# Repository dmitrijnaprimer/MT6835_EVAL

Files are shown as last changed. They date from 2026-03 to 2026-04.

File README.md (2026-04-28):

# MT6835_EVAL

Evaluation system for the MagnTek MT6835 21-bit magnetic encoder IC.

Measures MT6835 nonlinearity against a LIR-DA237T 23-bit optical reference encoder, computes NLC (Non-Linearity Compensation) correction tables, visualizes results.
Built as a platform for evaluation and a proof-of-concept, pieces of this work can be used for real in-system calibration fixtures.

## Used hardware

- **MCU:** STM32H503CBT6 (not recommended — any dual-SPI MCU will do)
- **Evaluated encoder:** MagnTek MT6835 (SPI, 21-bit)
- **Reference encoder:** LIR-DA237T (BiSS-C, 23-bit, ±0.0083°)
- **Motor driver:** TMC2225 (STEP/DIR, 32 microsteps)
- **Motor:** 400 steps/rev (0.9°), 12 800 microsteps/rev
- **Fixture:** ASA 3D-printed horisontal mechanical bench, 8mm main shaft, ball bearing holder.

Single-shaft fixture — both encoders and the stepper on the same shaft. Magnet is fixed on the shaft end via replaceable adapter. Adapters available for 4×2 mm round, 6×2.5 mm round, 6×6×6 mm cube magnets. Optimal air gap: 0.5–2.0 mm.

## Key findings

| Parameter | Value |
|---|---|
| NLC LSB | 360°/2¹⁸ = 0.001373° (8 counts of 21-bit angle) |
| NLC packing | MSB-first, 6-bit two's complement |
| NLC grid | indexed by raw magnetic angle (before ZERO_POS) |
| DC removal | chip subtracts the mean automatically |
| NLC range | ±0.044° per point (±32 LSB) |

## Quick Start — Python GUI

```bash
cd software
python -m venv .venv
source .venv/bin/activate
pip install -r requirements.txt
python main.py
```

## Quick Start — Firmware

### Prerequisites

- [ARM GNU Toolchain](https://developer.arm.com/downloads/-/arm-gnu-toolchain-downloads) (`arm-gnu-toolchain-15.2.rel1-x86_64-arm-none-eabi`)
- CMake ≥ 3.22
- Ninja (or another CMake generator)

### Build

```bash
cd firmware/MT6835_EVAL_STM32H503
cmake --preset=Debug
cmake --build --preset=Debug
```

Output: `build/Debug/MT6835_EVAL_01.elf` (`.bin`, `.hex`).

### Flash

Via ST-Link (OpenOCD, STM32CubeProgrammer, or `st-flash`):

```bash
st-flash write build/Debug/MT6835_EVAL_01.bin 0x08000000
```

Or load the `.elf` directly from IDE (STM32CubeIDE, VS Code + Cortex-Debug), or with CubeProgrammer.

## Evaluation workflow

1. **User Auto-Cal** — built-in MT6835 calibration at 50–100 RPM (gets INL to ~±0.07°)
2. **Home** — move shaft to LIR zero position
3. **Set Zero Pos** — set MT6835 ZERO_POS (must be done before NLC, never after)
4. **Collect Data** — stepped measurement at 256 positions across 360°
5. **Generate NLC** — computes correction table from collected error profile
6. **Upload NLC** — writes table to MT6835 registers + EEPROM
7. **Collect Data** again to verify improvement

## Project structure

```
software/         — Python GUI (PyQt5) + calibration logic
firmware/         — STM32 firmware (CMake, C)
data/             — collected CSV data (gitignored)
  nlc/            — generated NLC hex files (gitignored)
construction/     — mechanical STEP files (see note below)
docs/             — technical report, datasheets
```

### Construction files

The `construction/` folder contains individual STEP files for each 3D printed part — **no assembly file is provided**. These are reference geometry only.

## License

MIT

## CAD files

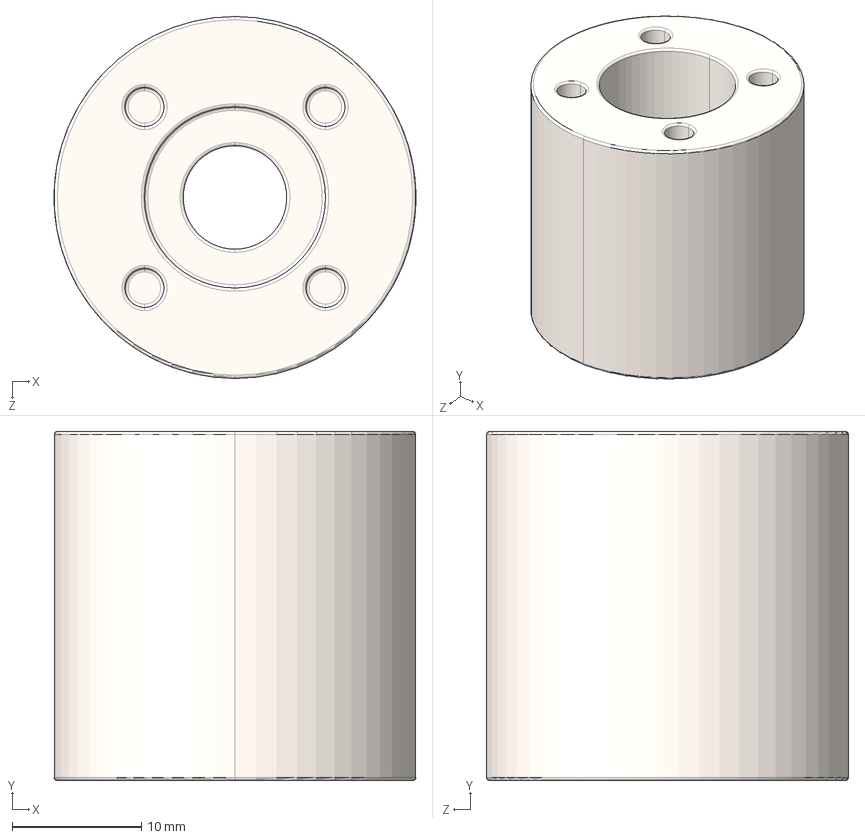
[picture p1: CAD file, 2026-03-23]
construction/STEP/shaft/main-shaft_bearing-block.STEP
28.0 x 27.0 x 28.0 mm

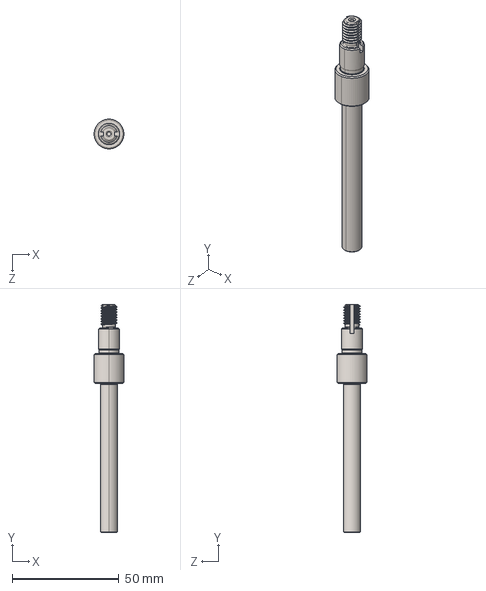
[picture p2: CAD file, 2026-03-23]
construction/STEP/shaft/main-shaft_shaft.STEP
14.0 x 107.0 x 14.0 mm

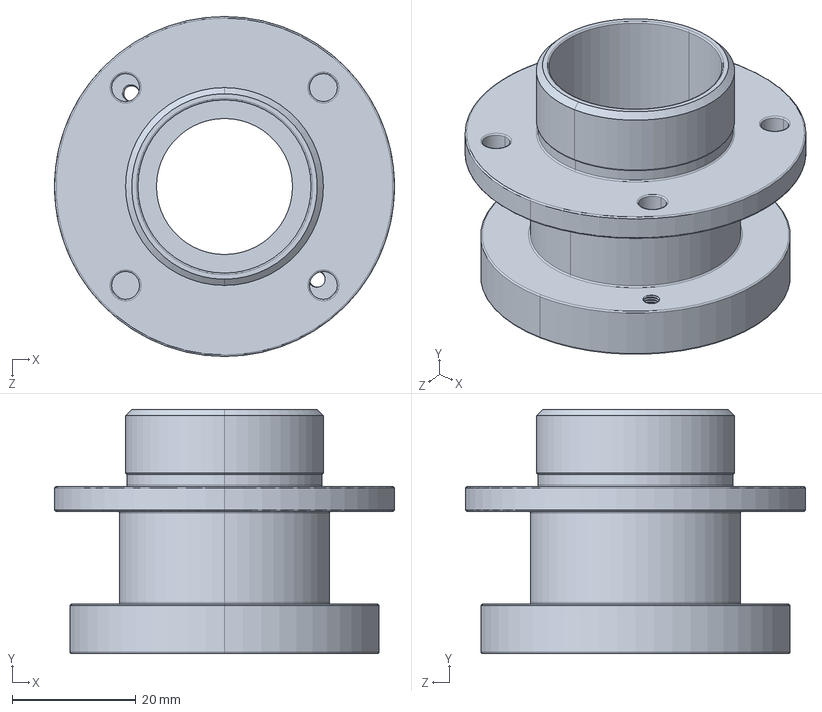
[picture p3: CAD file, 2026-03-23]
construction/STEP/shaft/main-shaft_flange.STEP
55.0 x 39.5 x 55.0 mm

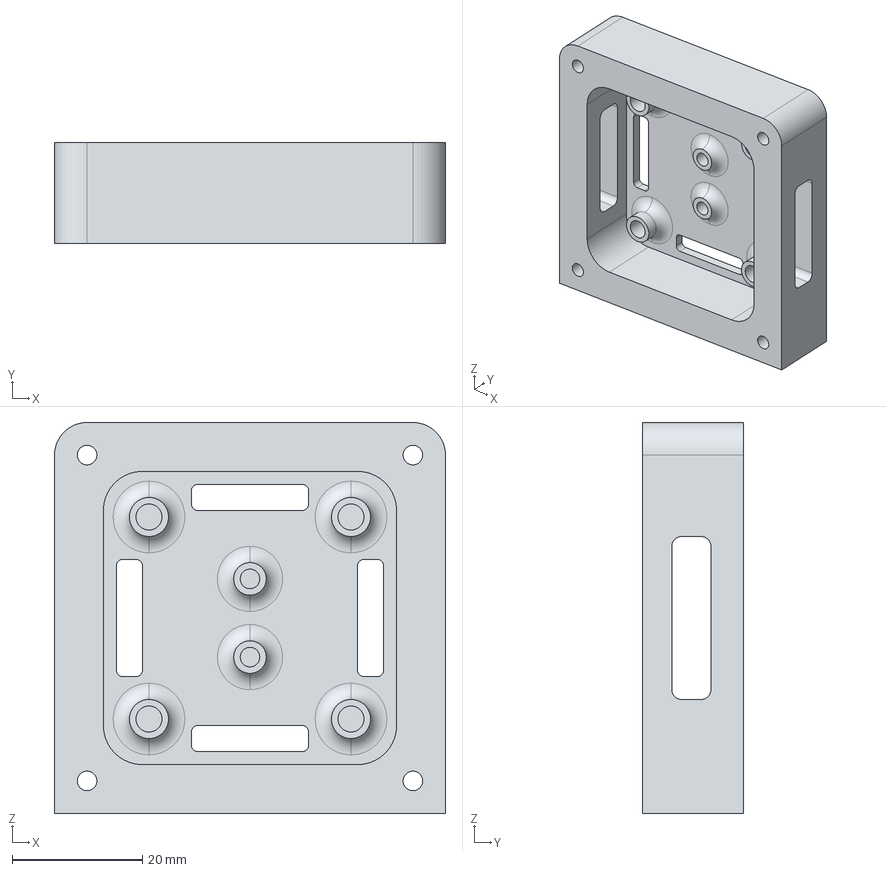
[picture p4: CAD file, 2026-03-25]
construction/STEP/encoder-stand_plastic/encoder-stand_magnetic-encoder-holder-base.STEP
60.0 x 15.5 x 60.0 mm

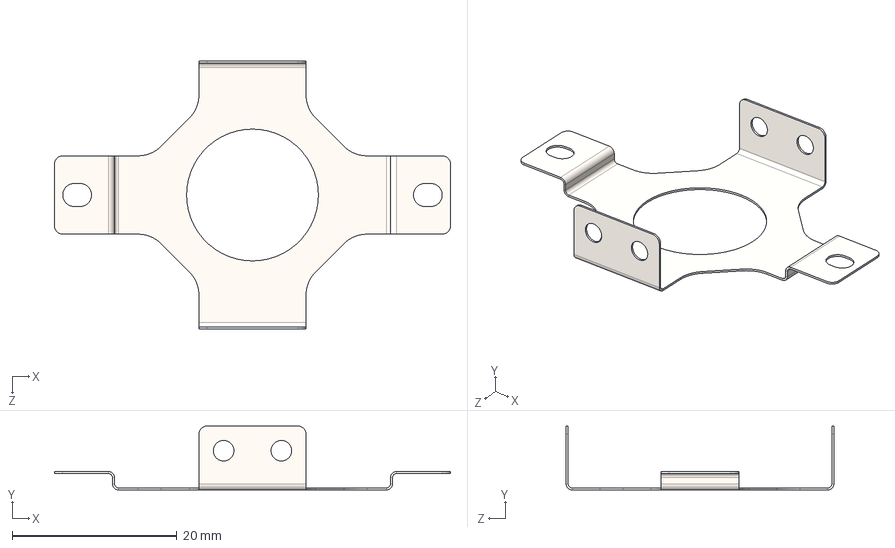
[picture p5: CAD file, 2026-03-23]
construction/STEP/LIR-DA237T/LIR-DA237T_CLIP.STEP
48.1 x 7.77 x 32.5 mm

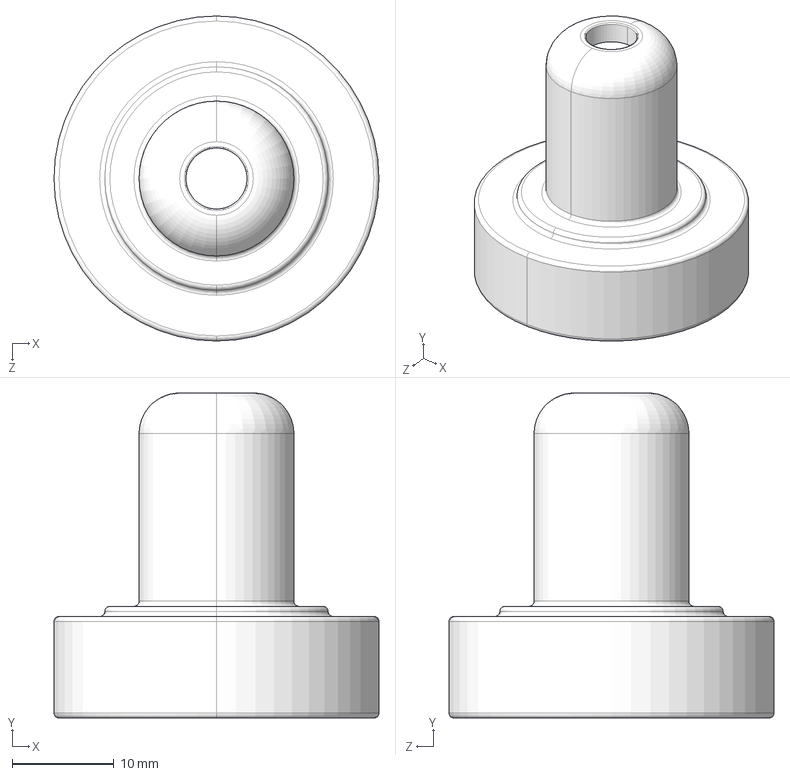
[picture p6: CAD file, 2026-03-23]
construction/STEP/encoder-stand_plastic/encoder-stand_magnet-holder_6x2.5-round.STEP
32.0 x 32.0 x 32.0 mm

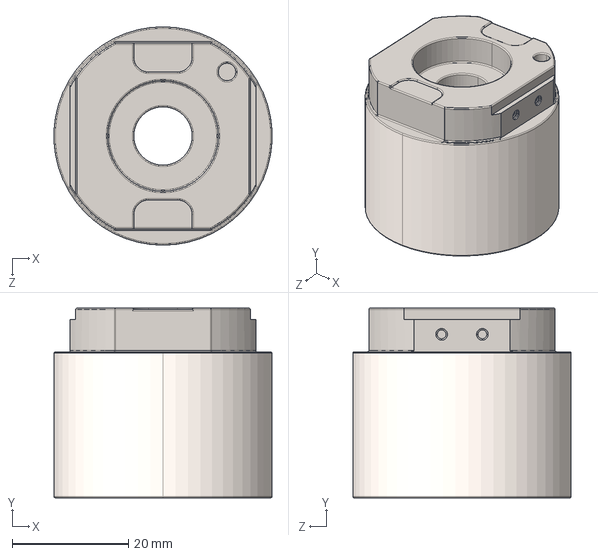
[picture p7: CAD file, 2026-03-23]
construction/STEP/LIR-DA237T/LIR-DA237T_BODY.STEP
37.4 x 32.6 x 37.5 mm

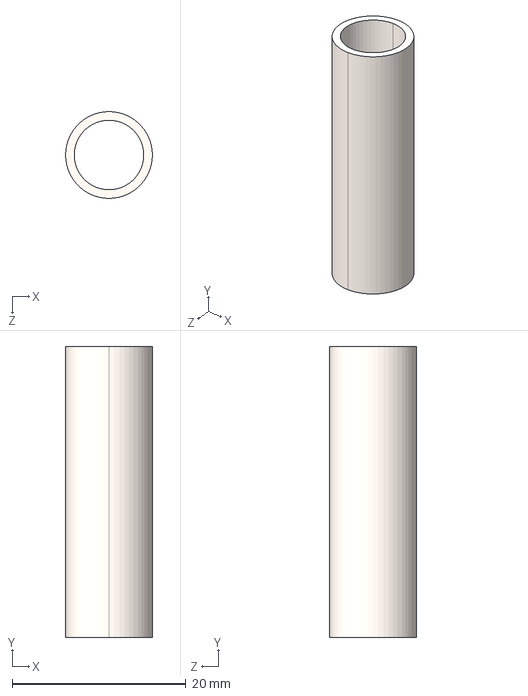
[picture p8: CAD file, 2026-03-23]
construction/STEP/LIR-DA237T/LIR-DA237T_SHAFT.STEP
10.0 x 33.5 x 10.0 mm

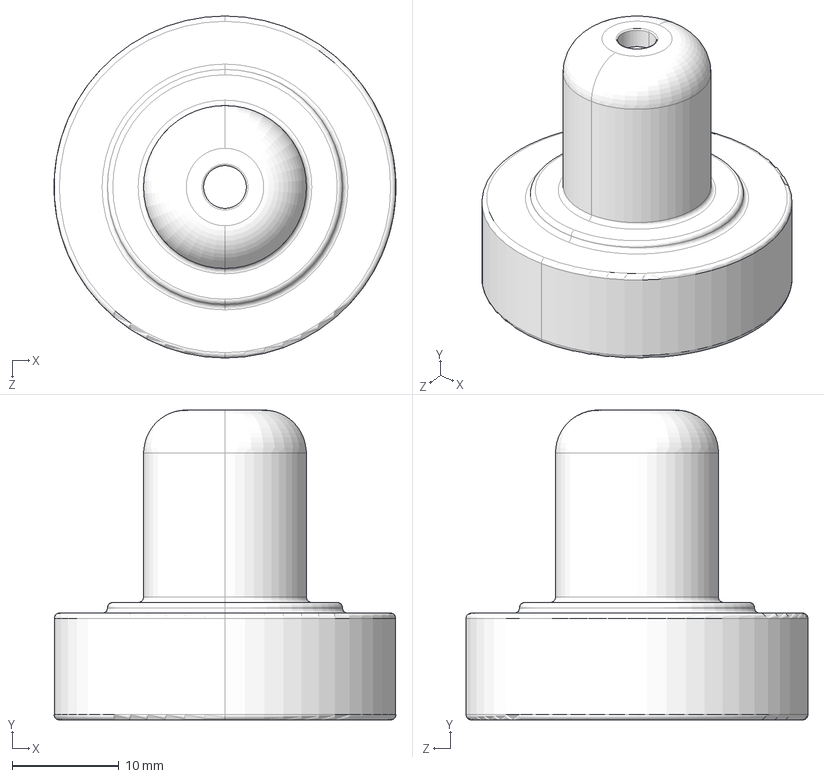
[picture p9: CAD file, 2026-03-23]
construction/STEP/encoder-stand_plastic/encoder-stand_magnet-holder_4x2-round_shortened.STEP
32.0 x 29.0 x 32.0 mm

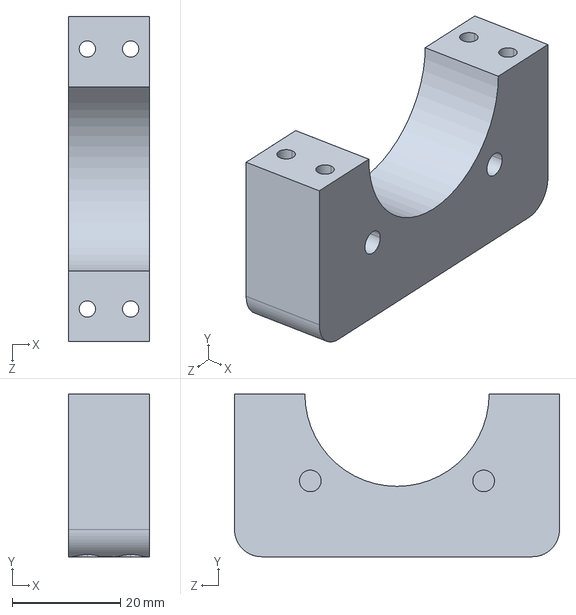
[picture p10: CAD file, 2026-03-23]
construction/STEP/encoder-stand_plastic/encoder-stand_flange-support-top.STEP
15.0 x 30.0 x 60.0 mm

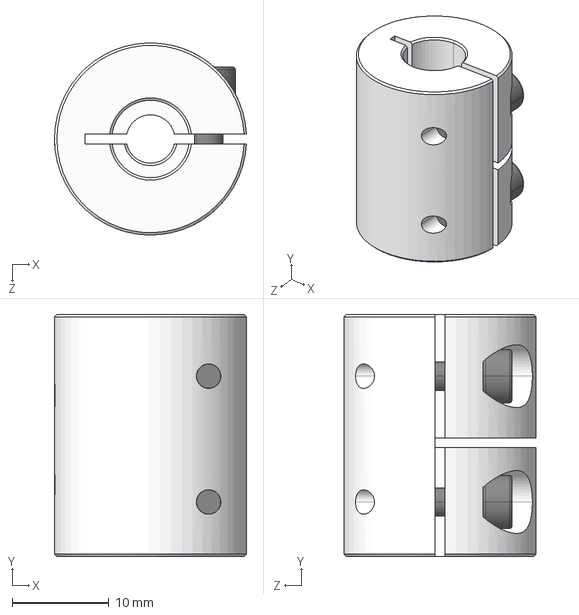
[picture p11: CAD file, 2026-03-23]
construction/STEP/shaft/5mm to 8mm rigid shaft coupler v2.STEP
19.8 x 25.0 x 19.8 mm

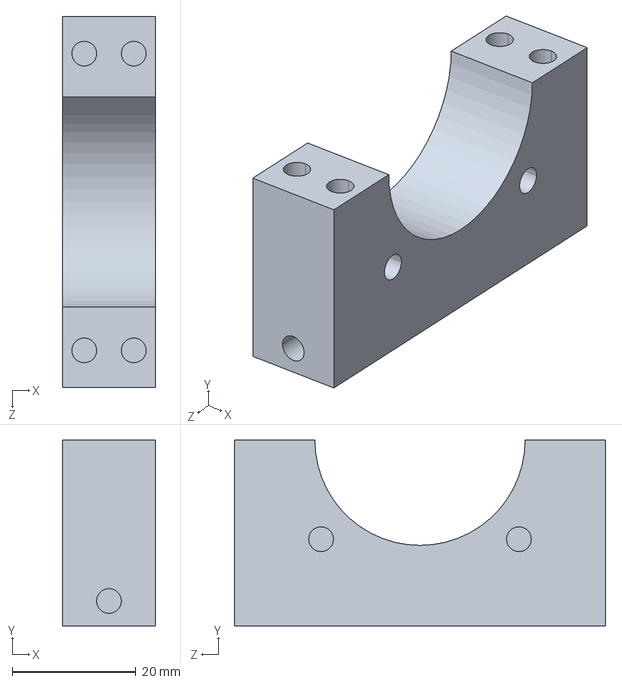
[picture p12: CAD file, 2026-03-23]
construction/STEP/encoder-stand_plastic/encoder-stand_flange-support-bottom.STEP
15.0 x 30.0 x 60.0 mm

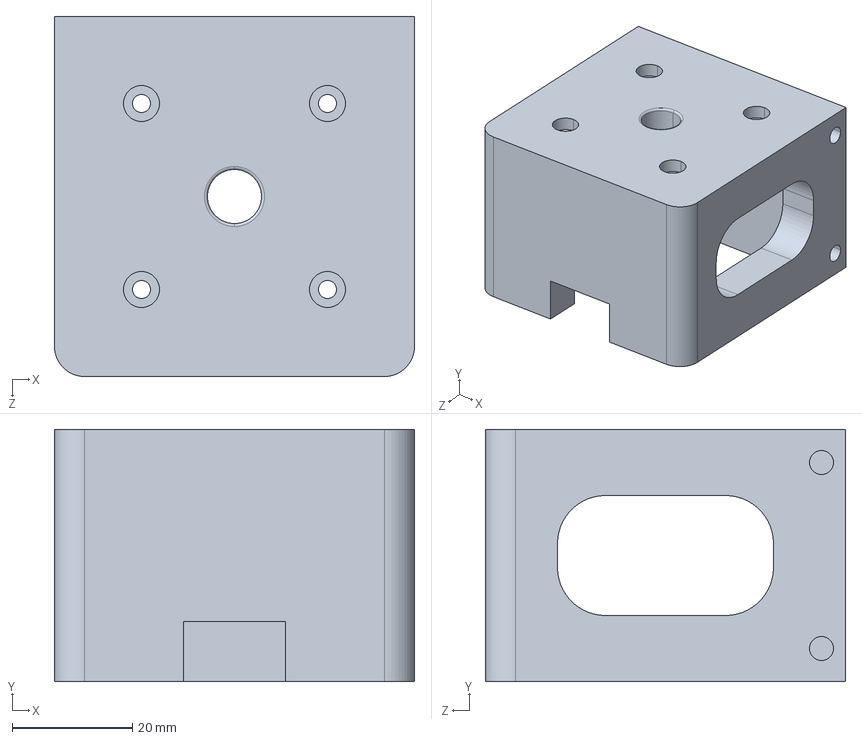
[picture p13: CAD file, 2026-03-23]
construction/STEP/encoder-stand_plastic/encoder-stand_motor-mount.STEP
60.0 x 42.0 x 60.0 mm

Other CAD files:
construction/STEP/shaft/main-shaft_assy.STEP
construction/STEP/encoder-stand_plastic/encoder-stand_bearing-support-assy.STEP
construction/STEP/encoder-stand_plastic/encoder-stand_flange-support-assy.STEP
construction/STEP/encoder-stand_plastic/encoder-stand_magnetic-encoder-holder-assy.STEP
construction/STEP/LIR-DA237T/LIR-DA237T.STEP
construction/STEP/encoder-stand_plastic/encoder-stand_base.STEP
construction/STEP/encoder-stand_plastic/encoder-stand_bearing-support-base.STEP
construction/STEP/encoder-stand_plastic/encoder-stand_magnet-holder_4x2-round.STEP
construction/STEP/encoder-stand_plastic/encoder-stand_magnet-holder_6x2.5-round_shortened.STEP
construction/STEP/encoder-stand_plastic/encoder-stand_magnet-holder_6x6-cube.STEP

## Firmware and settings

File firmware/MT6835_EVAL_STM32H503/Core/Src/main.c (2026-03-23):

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
/* Includes ------------------------------------------------------------------*/
#include "main.h"
#include "gpio.h"
#include "icache.h"
#include "spi.h"
#include "tim.h"
#include "usart.h"

/* USER CODE BEGIN Includes */
#include "encoders.h"
#include "motor_control.h"
#include "stm32h5xx_hal.h"
#include "uartcmd_handler.h"

/* USER CODE END Includes */


/* USER CODE BEGIN PV */
#define UART_RX_BUFFER_SIZE 512
char uart_rx_buffer[UART_RX_BUFFER_SIZE] = {0};
uint32_t uart_rx_index = 0;
bool uart_command_ready = false;
uint32_t led_blink_counter = 0;
bool homed_flag_for_led = false;
/* USER CODE END PV */

void SystemClock_Config(void);
void PeriphCommonClock_Config(void);
/**
 * @brief  The application entry point.
 * @retval int
 */
int main(void) {

  /* MCU Configuration--------------------------------------------------------*/

  /* Reset of all peripherals, Initializes the Flash interface and the Systick.
   */
  HAL_Init();

  /* Configure the system clock */
  SystemClock_Config();

  /* Configure the peripherals common clocks */
  PeriphCommonClock_Config();

  /* Initialize all configured peripherals */
  MX_GPIO_Init();
  MX_SPI1_Init();
  MX_TIM2_Init();
  MX_TIM3_Init();
  MX_USART1_UART_Init();
  MX_ICACHE_Init();
  MX_SPI2_Init();
  MX_TIM1_Init();
  /* USER CODE BEGIN 2 */
  ENC_Init();
  MC_Init();

  HAL_GPIO_WritePin(LED_3_GPIO_Port, LED_3_Pin, GPIO_PIN_RESET);
  HAL_GPIO_WritePin(LED_5_GPIO_Port, LED_5_Pin, GPIO_PIN_RESET);
  HAL_GPIO_WritePin(MT6835_CAL_EN_GPIO_Port, MT6835_CAL_EN_Pin, GPIO_PIN_RESET);
  HAL_GPIO_WritePin(LED_2_GPIO_Port, LED_2_Pin, GPIO_PIN_RESET);

  HAL_UART_Transmit(&huart1, (uint8_t *)"System Ready\n", 38, HAL_MAX_DELAY);
  /* USER CODE END 2 */

  /* Infinite loop */
  /* USER CODE BEGIN WHILE */
  while (1) {
    /* USER CODE END WHILE */

    /* USER CODE BEGIN 3 */
    if (HAL_GPIO_ReadPin(TMC2225_EN_GPIO_Port, TMC2225_EN_Pin) ==
        GPIO_PIN_RESET) {
      HAL_GPIO_WritePin(LED_4_GPIO_Port, LED_4_Pin,
                        GPIO_PIN_SET); // Motor enabled
    } else {
      HAL_GPIO_WritePin(LED_4_GPIO_Port, LED_4_Pin, GPIO_PIN_RESET);
    }

    if (homed_flag_for_led) {
      HAL_GPIO_WritePin(LED_0_GPIO_Port, LED_0_Pin, GPIO_PIN_SET); // Homed
    } else {
      HAL_GPIO_WritePin(LED_0_GPIO_Port, LED_0_Pin, GPIO_PIN_RESET);
    }

    led_blink_counter++;
    if (led_blink_counter >= 50000) {
      HAL_GPIO_TogglePin(LED_5_GPIO_Port, LED_5_Pin); // Slow blink
      led_blink_counter = 0;

      // Update LED 3 based on PWM Duty Cycle
      float pwm = ENC_GetMT6835PWMDutyCyclePercent();
      if (pwm > 95.0f) {
        HAL_GPIO_WritePin(LED_3_GPIO_Port, LED_3_Pin, GPIO_PIN_SET); // Solid ON
      } else if (pwm >= 25.0f && pwm <= 95.0f) {
        HAL_GPIO_TogglePin(LED_3_GPIO_Port, LED_3_Pin); // Blink
      } else {
        HAL_GPIO_WritePin(LED_3_GPIO_Port, LED_3_Pin, GPIO_PIN_RESET); // OFF
      }
    }

    if (HAL_GPIO_ReadPin(MT6835_CAL_EN_GPIO_Port, MT6835_CAL_EN_Pin) ==
        GPIO_PIN_SET) {
      HAL_GPIO_WritePin(LED_2_GPIO_Port, LED_2_Pin,
                        GPIO_PIN_SET); // MT6835 Cal enabled
    } else {
      HAL_GPIO_WritePin(LED_2_GPIO_Port, LED_2_Pin, GPIO_PIN_RESET);
    }

    uint8_t rx_char;
    if (HAL_UART_Receive(&huart1, &rx_char, 1, 0) == HAL_OK) {
      if (rx_char == '\n' || rx_char == '\r' ||
          uart_rx_index >= sizeof(uart_rx_buffer) - 1) {
        uart_rx_buffer[uart_rx_index] = '\0';
        if ((rx_char == '\n' || rx_char == '\r') && uart_rx_index > 0) {
          uart_command_ready = true;
        }
        uart_rx_index = 0;
      } else {
        uart_rx_buffer[uart_rx_index++] = rx_char;
      }
    }

    if (uart_command_ready) {
      UART_CMD_ProcessCommand(uart_rx_buffer);
      uart_command_ready = false;
      extern bool UART_CMD_GetHomedState(void);
      homed_flag_for_led = UART_CMD_GetHomedState();
    }
  }
  /* USER CODE END 3 */
}

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


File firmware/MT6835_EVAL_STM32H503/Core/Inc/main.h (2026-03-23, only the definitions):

#define MT6835_CSN_Pin GPIO_PIN_1
#define MT6835_CSN_GPIO_Port GPIOA
#define LED_0_Pin GPIO_PIN_3
#define LED_0_GPIO_Port GPIOA
#define MT6835_MOSI_Pin GPIO_PIN_4
#define MT6835_MOSI_GPIO_Port GPIOA
#define MT6835_SCK_Pin GPIO_PIN_5
#define MT6835_SCK_GPIO_Port GPIOA
#define LED_1_Pin GPIO_PIN_6
#define LED_1_GPIO_Port GPIOA
#define LED_2_Pin GPIO_PIN_7
#define LED_2_GPIO_Port GPIOA
#define LED_3_Pin GPIO_PIN_0
#define LED_3_GPIO_Port GPIOB
#define LIR_DA237T_SCK_Pin GPIO_PIN_2
#define LIR_DA237T_SCK_GPIO_Port GPIOB
#define LED_4_Pin GPIO_PIN_10
#define LED_4_GPIO_Port GPIOB
#define MT6835_CAL_EN_Pin GPIO_PIN_12
#define MT6835_CAL_EN_GPIO_Port GPIOB
#define MT6835_PWM_Pin GPIO_PIN_13
#define MT6835_PWM_GPIO_Port GPIOB
#define TMC2225_DIR_Pin GPIO_PIN_9
#define TMC2225_DIR_GPIO_Port GPIOA
#define TMC2225_EN_Pin GPIO_PIN_10
#define TMC2225_EN_GPIO_Port GPIOA
#define LIR_DA237T_DATA_Pin GPIO_PIN_15
#define LIR_DA237T_DATA_GPIO_Port GPIOA
#define TMC2225_STEP_Pin GPIO_PIN_3
#define TMC2225_STEP_GPIO_Port GPIOB
#define MT6835_MISO_Pin GPIO_PIN_4
#define MT6835_MISO_GPIO_Port GPIOB
#define TMC2225_MICROSTEPS_Pin GPIO_PIN_7
#define TMC2225_MICROSTEPS_GPIO_Port GPIOB
#define LED_5_Pin GPIO_PIN_8
#define LED_5_GPIO_Port GPIOB

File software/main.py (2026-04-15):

"""Encoder evaluation GUI for MT6835 motor control.

Provides serial communication with the eval board, motor control,
MT6835 configuration (HYST, BW, NLC, ZERO_POS), stepped data
collection, and a visualization window.
"""

import sys
import time

import serial
import serial.tools.list_ports
from PyQt5.QtCore import QThread, QTimer, pyqtSignal
from PyQt5.QtWidgets import (
    QApplication,
    QCheckBox,
    QComboBox,
    QGridLayout,
    QGroupBox,
    QHBoxLayout,
    QInputDialog,
    QLabel,
    QLineEdit,
    QMainWindow,
    QMessageBox,
    QPlainTextEdit,
    QProgressBar,
    QPushButton,
    QVBoxLayout,
    QWidget,
)

from calibration import CalibrationManager
from visualize import VisualizationWindow

FONT_MAIN = "font-family: 'Segoe UI','Consolas',monospace; font-size: 12px;"
FONT_CONSOLE = "font-family: 'Consolas','Courier New',monospace; font-size: 11px;"
BTN_WIDTH = 120

QUIET_COMMANDS = {
    "STATUS",
    "MOVE_CW_STEPS",
    "MOVE_CCW_STEPS",
    "SET_STEPS",
    "SET_SPEED",
    "TMC2225_MS_32",
}

LIR_BIT_DEPTH = 23
USTEPS_PER_REV = 12800
DEG_PER_USTEP = 360.0 / USTEPS_PER_REV

"""Movement presets: (label, microsteps). All are exact multiples of one microstep."""
MOVE_PRESETS = [
    ("Continuous", 0),
    ("0.028° (1 µst)", 1),
    ("0.113° (4 µst)", 4),
    ("0.225° (8 µst)", 8),
    ("0.450° (16 µst)", 16),
    ("0.900° (32 µst)", 32),
    ("1.406° (50 µst)", 50),
    ("1.800° (64 µst)", 64),
    ("2.813° (100 µst)", 100),
    ("5.625° (200 µst)", 200),
    ("11.25° (400 µst)", 400),
    ("22.50° (800 µst)", 800),
    ("45.00° (1600 µst)", 1600),
    ("90.00° (3200 µst)", 3200),
    ("180.0° (6400 µst)", 6400),
    ("360.0° (12800 µst)", 12800),
]


class SerialReader(QThread):
    """Background thread for reading UART data line-by-line.

    Emits ``data_received(str)`` for each complete line,
    ``connection_status_changed(bool)`` on connect/disconnect,
    and ``error_occurred(str)`` on errors.
    """

    data_received = pyqtSignal(str)
    connection_status_changed = pyqtSignal(bool)
    error_occurred = pyqtSignal(str)

    def __init__(self, port_name, baudrate=115200):
        """Open a serial reader on the given port.

        :param port_name: COM port string (e.g. ``COM3``).
        :param baudrate: Baud rate (default 115200).
        """
        super().__init__()
        self.port_name = port_name
        self.baudrate = baudrate
        self.running = False
        self.serial_port = None
        self.buffer = ""

    def run(self):
        """Thread entry point. Opens port and reads until stopped."""
        try:
            self.serial_port = serial.Serial(
                self.port_name,
                self.baudrate,
                timeout=0.1,
                parity=serial.PARITY_NONE,
                stopbits=serial.STOPBITS_ONE,
                bytesize=serial.EIGHTBITS,
                rtscts=False,
                dsrdtr=False,
            )
            self.running = True
            self.connection_status_changed.emit(True)
            while self.running:
                try:
                    if self.serial_port.in_waiting > 0:
                        raw = self.serial_port.read(self.serial_port.in_waiting)
                        self.buffer += raw.decode("utf-8", errors="ignore")
                        while "\n" in self.buffer:
                            line, self.buffer = self.buffer.split("\n", 1)
                            line = line.strip()
                            if line:
                                self.data_received.emit(line)
                except Exception as e:
                    self.error_occurred.emit(f"Read error: {e}")
                    break
                self.msleep(5)
        except Exception as e:
            self.error_occurred.emit(f"Connection error: {e}")
        finally:
            self.running = False
            if self.serial_port and self.serial_port.is_open:
                self.serial_port.close()
            self.connection_status_changed.emit(False)

    def stop(self):
        """Signal the thread to stop and close the serial port."""
        self.running = False
        if self.serial_port and self.serial_port.is_open:
            try:
                self.serial_port.reset_input_buffer()
                self.serial_port.reset_output_buffer()
                self.serial_port.close()
            except Exception:
                pass


def _btn(text, callback, width=BTN_WIDTH):
    """Create a fixed-width QPushButton connected to a callback."""
    b = QPushButton(text)
    b.setFixedWidth(width)
    b.clicked.connect(callback)
    return b


def _get_int(combo):
    """Extract the leading integer from a combo box text like ``50 RPM``."""
    return int(combo.currentText().split()[0])
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

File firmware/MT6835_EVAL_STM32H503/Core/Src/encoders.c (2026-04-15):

/**
 * @file encoders.c
 * @brief Driver for MT6835 (SPI1) and LIR-DA237T (SPI2, BiSS-C).
 */

#include "encoders.h"
#include "main.h"
#include "stm32h5xx_hal.h"
#include "string.h"
#include <stdio.h>

extern SPI_HandleTypeDef hspi1;
extern SPI_HandleTypeDef hspi2;

#define MT6835_CRC8_POLY 0x07

#define LIR_NUM_BITS_DEFAULT 23
#define LIR_MIN_BITS 21
#define LIR_MAX_BITS 23

/* ---- LIR state ---- */
static volatile uint32_t lir_raw_cached = 0;
static volatile uint32_t lir_raw_physical = 0;
static volatile uint32_t lir_offset = 0;
static volatile float lir_degrees_cached = 0.0f;
static uint8_t lir_num_bits = LIR_NUM_BITS_DEFAULT;

/* ---- MT6835 state ---- */
static volatile uint32_t mt6835_raw_cached = 0;
static volatile uint32_t mt6835_raw_physical = 0;
static volatile float mt6835_degrees_cached = 0.0f;
static float mt6835_pwm_duty_percent = 0.0f;
static uint8_t mt6835_status_reg = 0;
static bool mt6835_crc_error = false;

/* ---- Debug ---- */
static uint8_t mt6835_debug_rx_buf[6] = {0};
static uint8_t mt6835_debug_calc_crc = 0;
static uint8_t mt6835_autocal_written = 0;
static uint8_t mt6835_autocal_readback = 0;

static uint64_t debug_spi_combined_word = 0;
static uint8_t debug_start_found_at = 0xFF;
static uint32_t debug_extracted_data = 0;
static uint8_t debug_calculated_crc = 0;
static uint8_t debug_received_crc = 0;
static uint8_t debug_crc_ok = 0;
static char debug_raw_sequence_str[66];

/* ================================================================== */
/* Helpers                                                            */
/* ================================================================== */

/** @brief Convert hex character to 4-bit value. */
static uint8_t hex_char_to_nibble(char c) {
  if (c >= '0' && c <= '9') return c - '0';
  if (c >= 'A' && c <= 'F') return c - 'A' + 10;
  if (c >= 'a' && c <= 'f') return c - 'a' + 10;
  return 0;
}

/** @brief Convert two hex characters to a byte. */
static uint8_t hex_to_byte(const char *hex) {
  return (hex_char_to_nibble(hex[0]) << 4) | hex_char_to_nibble(hex[1]);
}

/** @brief CRC8 for MT6835 (poly X^8+X^2+X+1, init 0x00). */
static uint8_t calculate_crc8_mt6835(const uint8_t *data, uint8_t len) {
  uint8_t crc = 0x00;
  for (int i = 0; i < len; i++) {
    crc ^= data[i];
    for (int j = 0; j < 8; j++) {
      if (crc & 0x80) crc = (crc << 1) ^ MT6835_CRC8_POLY;
      else crc <<= 1;
    }
  }
  return crc;
}

/** @brief CRC6 for BiSS-C protocol. */
static uint8_t calculate_crc6_bissc(uint64_t frame_word, uint8_t data_msb_pos,
                                    uint8_t num_data_bits) {
  uint8_t crc = 0x00;
  int total_bits = num_data_bits + 2;
  for (int i = 0; i < total_bits; i++) {
    int bit_pos = data_msb_pos - i;
    if (bit_pos < 0) break;
    uint8_t current_bit = (frame_word >> bit_pos) & 0x01;
    uint8_t msb = (crc >> 5) & 0x01;
    crc <<= 1;
    if (msb ^ current_bit) crc ^= 0x03;
    crc &= 0x3F;
  }
  return crc;
}

/* ================================================================== */
/* MT6835 PWM measurement                                             */
/* ================================================================== */

/** @brief Measure PWM duty cycle by busy-loop. Blocks ~1-2ms. */
void ENC_MeasureMT6835PWM(void) {
  uint32_t high_count = 0, low_count = 0, timeout;

  timeout = 100000;
  while (HAL_GPIO_ReadPin(MT6835_PWM_GPIO_Port, MT6835_PWM_Pin) == GPIO_PIN_SET && timeout--);
  if (timeout == 0) { mt6835_pwm_duty_percent = 100.0f; return; }

  timeout = 100000;
  while (HAL_GPIO_ReadPin(MT6835_PWM_GPIO_Port, MT6835_PWM_Pin) == GPIO_PIN_RESET && timeout--);
  if (timeout == 0) { mt6835_pwm_duty_percent = 0.0f; return; }

  timeout = 2000000;
  while (HAL_GPIO_ReadPin(MT6835_PWM_GPIO_Port, MT6835_PWM_Pin) == GPIO_PIN_SET && timeout--) high_count++;

  timeout = 2000000;
  while (HAL_GPIO_ReadPin(MT6835_PWM_GPIO_Port, MT6835_PWM_Pin) == GPIO_PIN_RESET && timeout--) low_count++;

  uint32_t total = high_count + low_count;
  mt6835_pwm_duty_percent = (total > 0) ? ((float)high_count / (float)total) * 100.0f : 0.0f;
}

/* ================================================================== */
/* MT6835 SPI register access                                         */
/* ================================================================== */

/** @brief Read one register byte via SPI1. */
uint8_t ENC_ReadMT6835Register(uint16_t address) {
  uint8_t tx_buf[3], rx_buf[3] = {0};
  tx_buf[0] = (MT6835_CMD_READ << 4) | ((address >> 8) & 0x0F);
  tx_buf[1] = address & 0xFF;
  tx_buf[2] = 0x00;
  HAL_GPIO_WritePin(MT6835_CSN_GPIO_Port, MT6835_CSN_Pin, GPIO_PIN_RESET);
  HAL_SPI_TransmitReceive(&hspi1, tx_buf, rx_buf, 3, 10);
  HAL_GPIO_WritePin(MT6835_CSN_GPIO_Port, MT6835_CSN_Pin, GPIO_PIN_SET);
  return rx_buf[2];
}

/** @brief Write one register byte via SPI1. */
void ENC_WriteMT6835Register(uint16_t address, uint8_t data) {
  uint8_t tx_buf[3];
  tx_buf[0] = (MT6835_CMD_WRITE << 4) | ((address >> 8) & 0x0F);
  tx_buf[1] = address & 0xFF;
  tx_buf[2] = data;
  HAL_GPIO_WritePin(MT6835_CSN_GPIO_Port, MT6835_CSN_Pin, GPIO_PIN_RESET);
  HAL_SPI_Transmit(&hspi1, tx_buf, 3, 10);
  HAL_GPIO_WritePin(MT6835_CSN_GPIO_Port, MT6835_CSN_Pin, GPIO_PIN_SET);
  for (volatile int i = 0; i < 100; i++);
}

/* ================================================================== */
/* MT6835 angle reading                                               */
/* ================================================================== */

/**
 * @brief Burst-read 21-bit angle with CRC8 check.
 *
 * Reads registers 0x003-0x006. On CRC failure the cached value is unchanged.
 * The returned angle has ZERO_POS already subtracted by the chip internally.
 */
uint32_t ENC_ReadMT6835Raw(void) {
  uint8_t tx_buf[6] = {0}, rx_buf[6] = {0};
  tx_buf[0] = (MT6835_CMD_BURST_READ << 4) | ((MT6835_REG_ANGLE_H >> 8) & 0x0F);
  tx_buf[1] = MT6835_REG_ANGLE_H & 0xFF;

  HAL_GPIO_WritePin(MT6835_CSN_GPIO_Port, MT6835_CSN_Pin, GPIO_PIN_RESET);
  HAL_SPI_TransmitReceive(&hspi1, tx_buf, rx_buf, 6, 10);
  HAL_GPIO_WritePin(MT6835_CSN_GPIO_Port, MT6835_CSN_Pin, GPIO_PIN_SET);

  memcpy(mt6835_debug_rx_buf, rx_buf, 6);

  uint32_t angle = ((uint32_t)rx_buf[2] << 13) |
                   ((uint32_t)rx_buf[3] << 5) |
                   ((uint32_t)(rx_buf[4] >> 3));
  mt6835_status_reg = rx_buf[4] & 0x07;

  uint8_t crc_data[3] = {rx_buf[2], rx_buf[3], rx_buf[4]};
  uint8_t calc_crc = calculate_crc8_mt6835(crc_data, 3);
  mt6835_debug_calc_crc = calc_crc;

  if (calc_crc == rx_buf[5]) {
    mt6835_crc_error = false;
    mt6835_raw_physical = angle;
    mt6835_raw_cached = angle;
    mt6835_degrees_cached = ((float)mt6835_raw_cached / 2097152.0f) * 360.0f;
  } else {
    mt6835_crc_error = true;
  }
  return mt6835_raw_cached;
}
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

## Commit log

2026-03-23 Update README
    Clarified the description of the single-shaft fixture and added information about the optimal air gap.
2026-03-25 STEP cleanup
    [0603 Capacitor.step.STEP, 0603 Capacitor001.step.STEP, 0603 Resistor.step.STEP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]

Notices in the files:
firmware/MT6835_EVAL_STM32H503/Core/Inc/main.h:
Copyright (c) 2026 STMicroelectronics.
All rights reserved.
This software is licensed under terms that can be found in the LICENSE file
